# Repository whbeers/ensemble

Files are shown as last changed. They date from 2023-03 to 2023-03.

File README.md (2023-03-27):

# Ensemble Fuzz Effect

This is a semi-original octave fuzz, based most directly on the Death By Audio "Octave Clang", but with many of my own tweaks and additions. Designed in [KiCAD](https://www.kicad.org).

The board is built on the ["Noise Floor"](https://github.com/whbeers/noise_floor) pedal platform, which provides basic power protection, audio IO, and a footswitch with LED indicator.

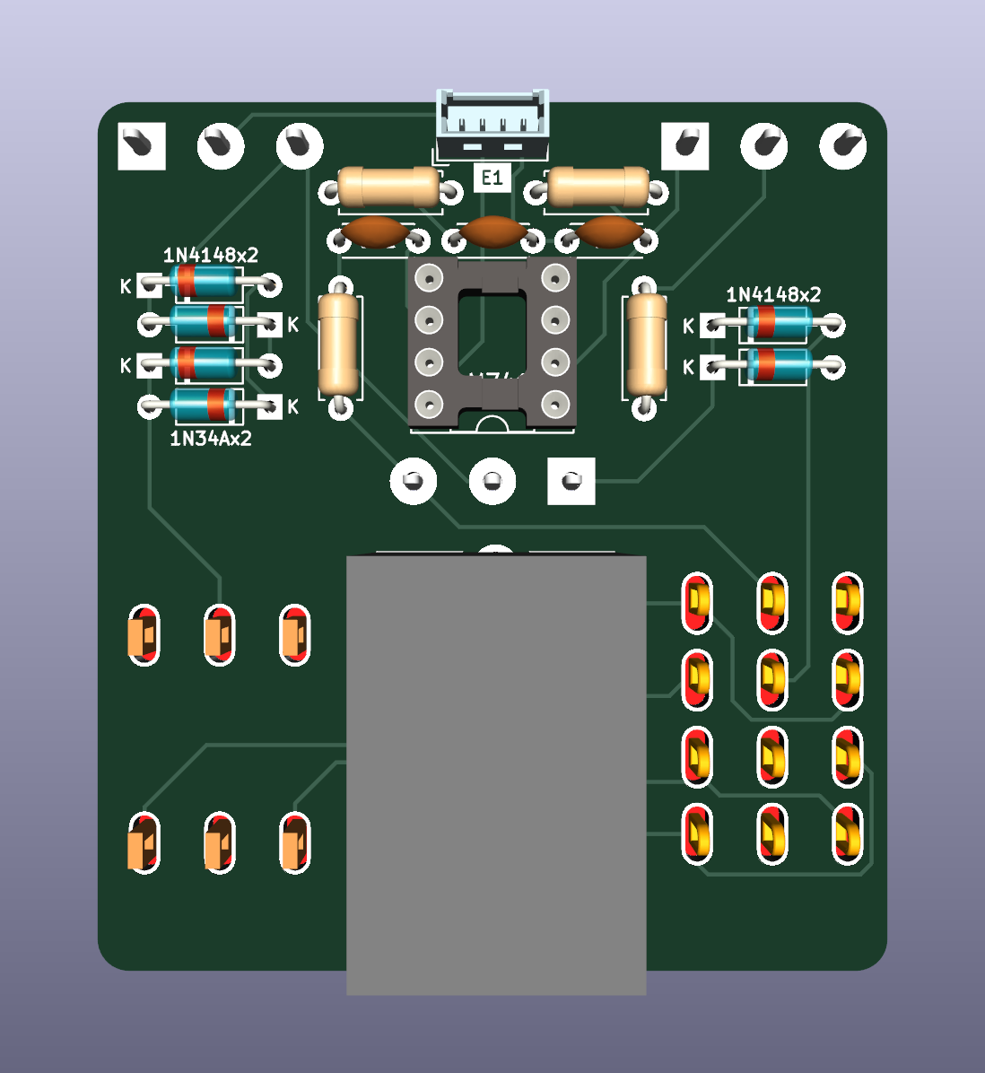
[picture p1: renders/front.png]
Front render

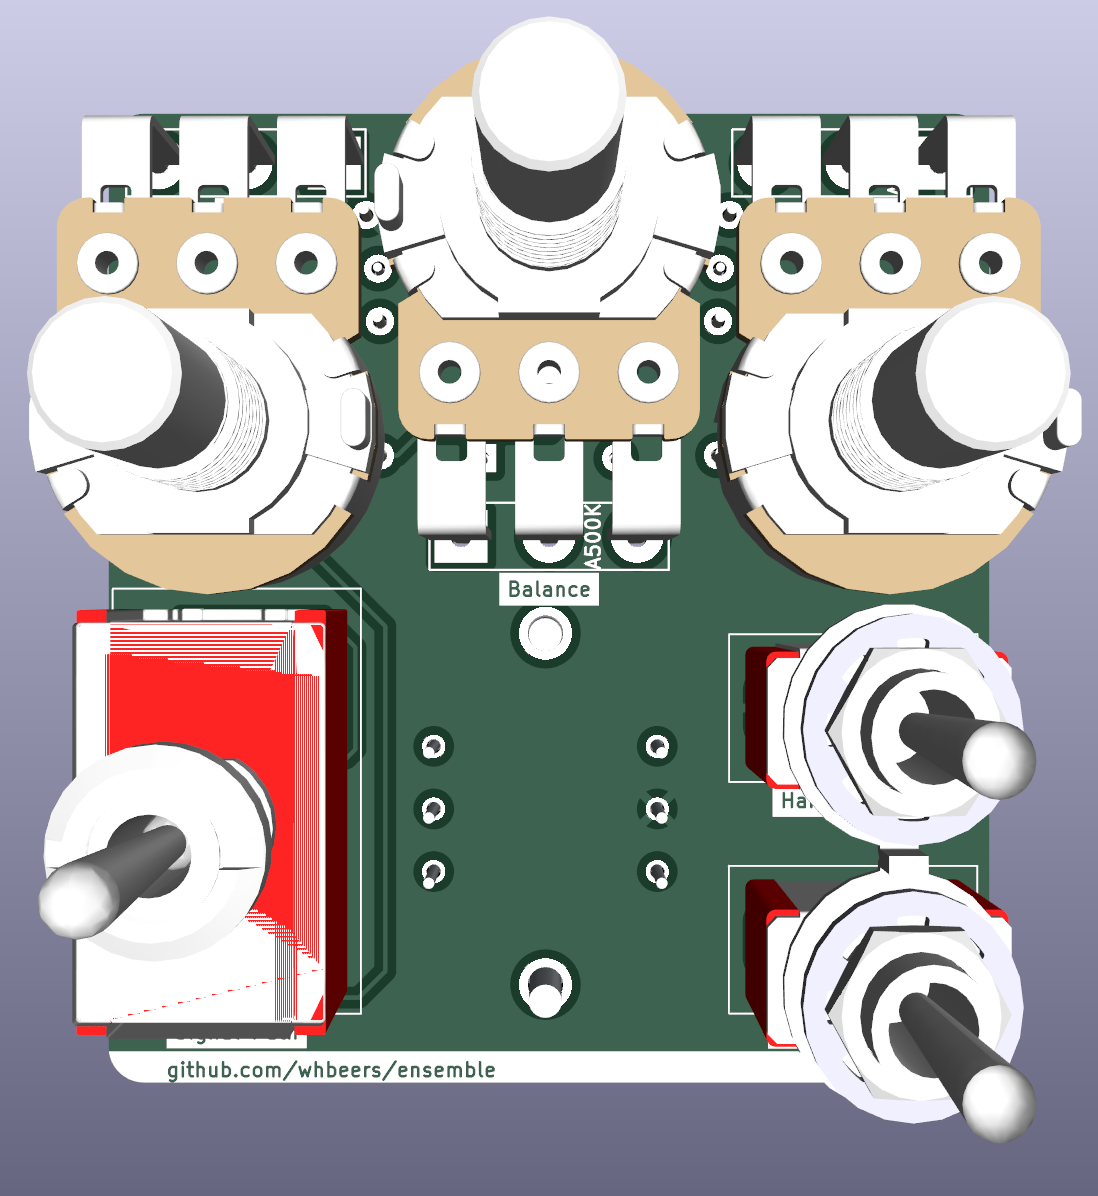
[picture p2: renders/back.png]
Back render

Schematic SVG
[Schematic PDF](schematics/ensemble-latest.pdf)

## Credit
I drew inspiration from a number of publicly-available octave fuzz schematics, but most directly public traces of the out-of-production [Death By Audio](https://deathbyaudio.com/) "Octave Clang" as portrayed in the PCBGuitarMania ["Death by Octaver" schematic](https://pcbguitarmania.com/product/death-by-octaver/), and by various contributors to the [thread at freestomboxes.org](https://www.freestompboxes.org/viewtopic.php?t=11122). I became interested in the effect after hearing the original maker, Oliver Ackermann, [demonstrate the Octave Clang](https://youtu.be/_RslAoTyIwk?t=2671) in a feature on EarthQuaker Devices' YouTube channel.

Thanks as always to the folks on the [freestompboxes.org](https://www.freestompboxes.org/) forum for feedback and suggestions.

Potentiometer 3D model courtesy [Vasily Kashirin](https://grabcad.com/vasily.kashirin-1).

SPDT toggle switch 3D model courtesy [Stephanie Schwecke](https://grabcad.com/stephanie.schwecke-1).

4PDT toggle switch 3D model courtesy [David Farrow](https://grabcad.com/library/4pdt-toggle-switch-1).

*I am not affiliated with any of the brands, sites, or products named in this overview.*

## My Modifications
Using what I could find out about Octave Clang as a basis, my circuit makes the following modifications:
 - added flexibility through three switchable voices for the octave stage:
   1. primary->secondary, full winding: a subtle driven octave effect
   2. secondary->primary, full winding: a clangorous metallic octave, most similar to the public demos of the Octave Clang
   3. secondary->primary, half winding: an even louder and more overt octave effect, thanks to the higher effective ratio of turns between secondary and primary windings. In this mode the octave effect is evident throughout most of the fretboard.
 - added a balance control to give further flexibility in the level of octave effect vs drive
 - added a (switchable) hard clipping stage to rein in the overall output level and add a very distinct, but still octave fuzz voice to the effect
 - tweaked component values to make the effect slightly more accessible across a range of volumes and gains (and to use more commonly-available values)
 - omitted the input-side tone control pot, as it tended to attenuate the signal to an unhelpful degree

## Versioning

My pcb designs utilize the following versioning scheme (I'll add to this as I produce more revisions):
 - v0.0XX: A candidate design that has not yet been produced and tested.
 - v0.XX: A design that has been produced, tested, and any initial errors addressed.

## Name
*The name "Ensemble" is a reflection of the nature of the effect (a blend of various octave fuzz and drive voices) and [security nerdery](https://www.usenix.org/system/files/sec19-chen-yuanliang.pdf).*

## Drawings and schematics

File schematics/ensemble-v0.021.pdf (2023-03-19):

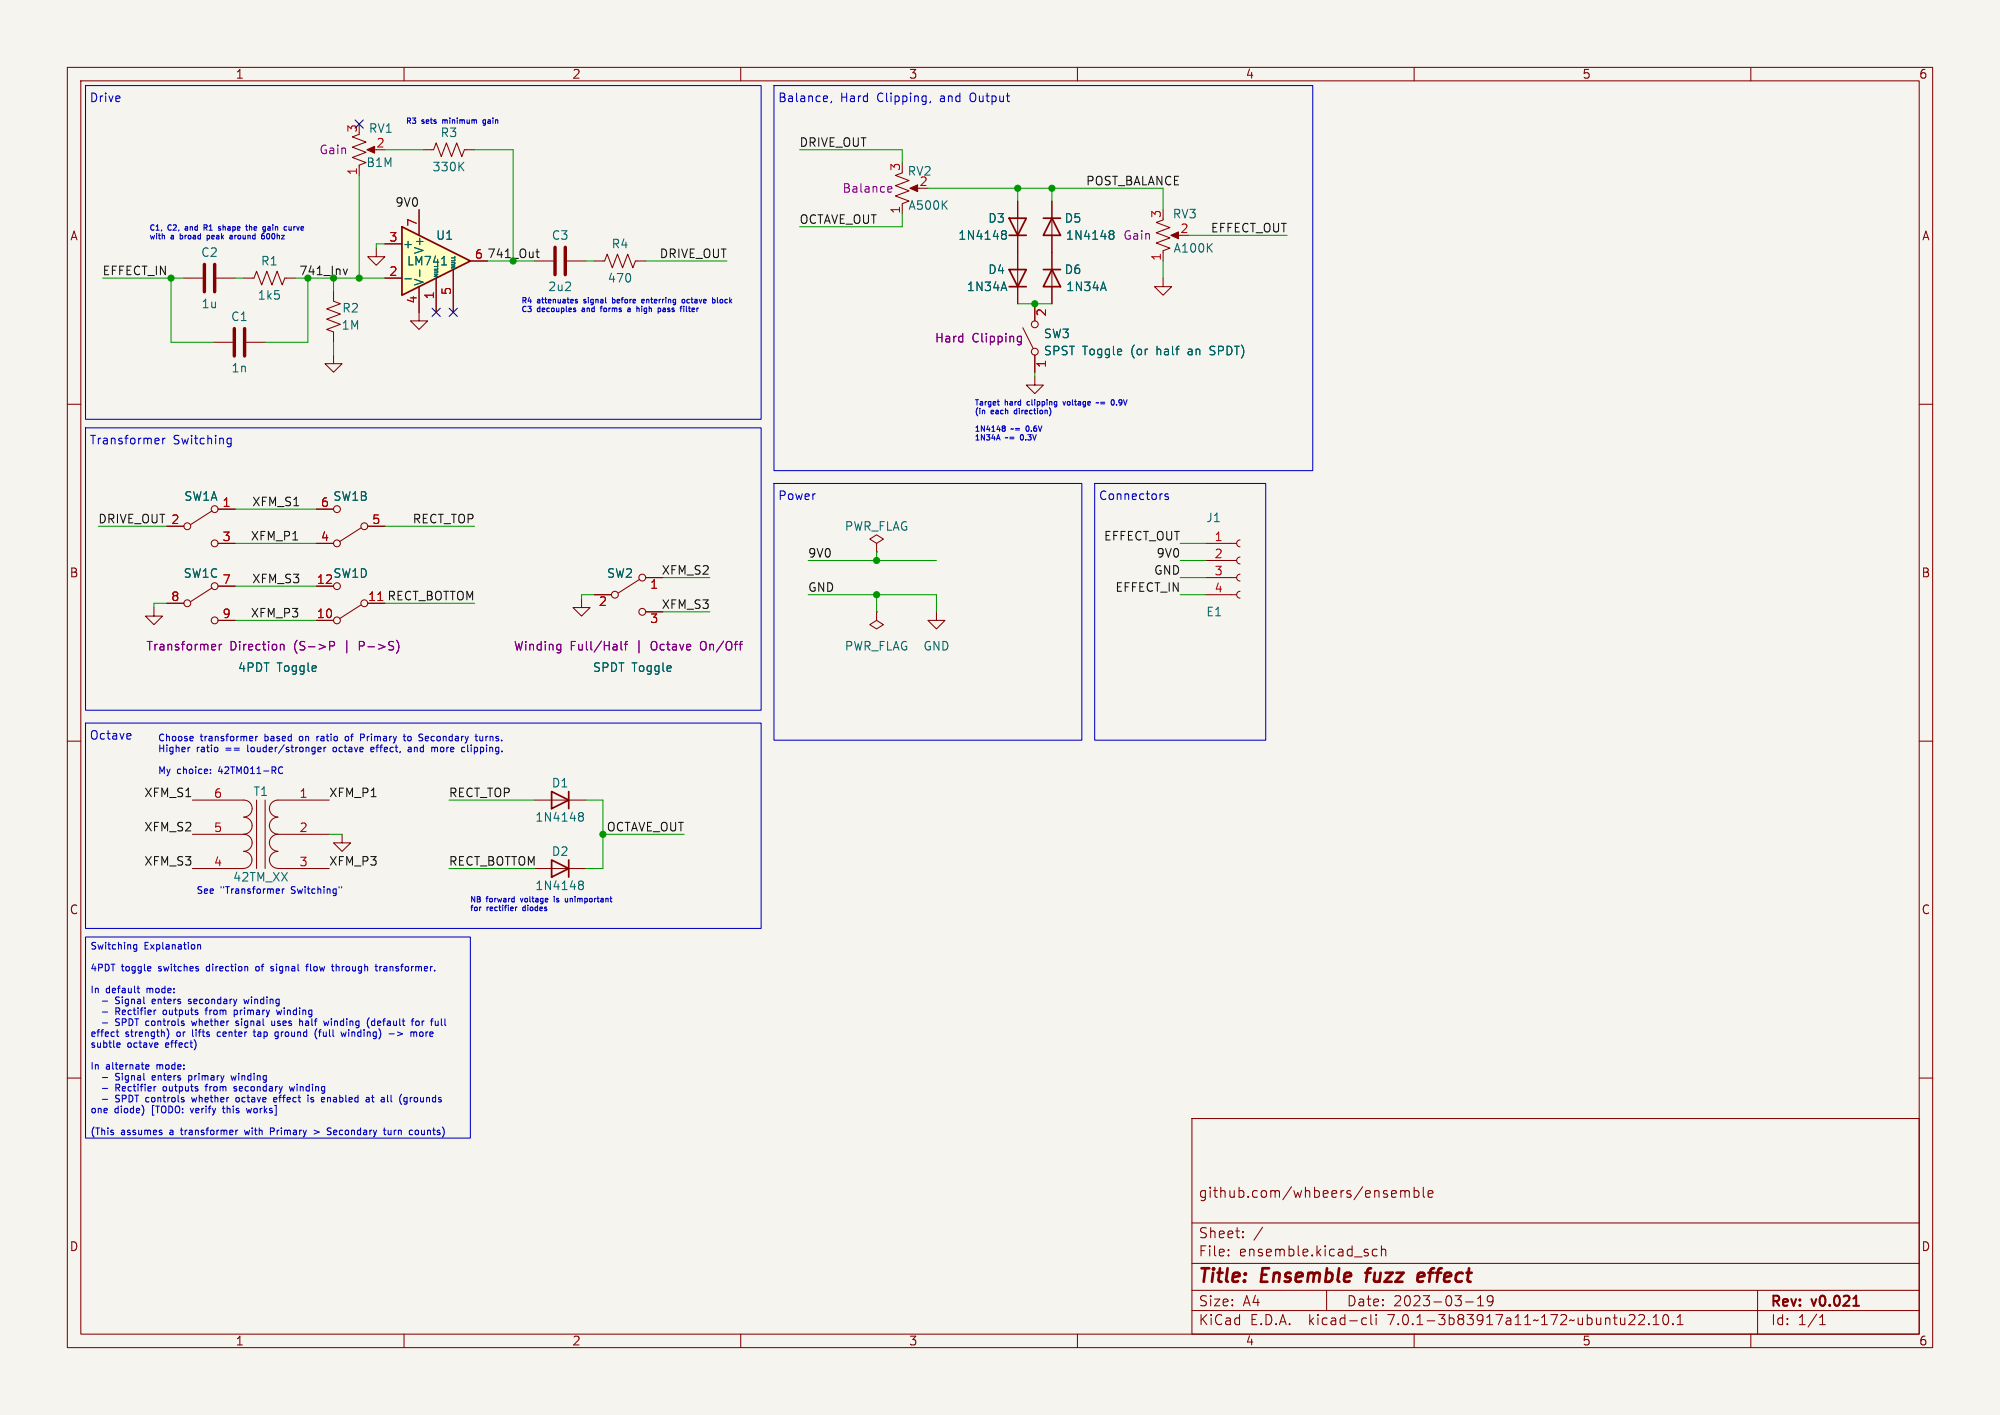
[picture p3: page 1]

SW3 SPST Toggle (or half an SPDT) Hard Clipping

Id: 1/1 Title: Ensemble fuzz effect File: ensemble.kicad_sch Sheet: / github.com/whbeers/ensemble GND

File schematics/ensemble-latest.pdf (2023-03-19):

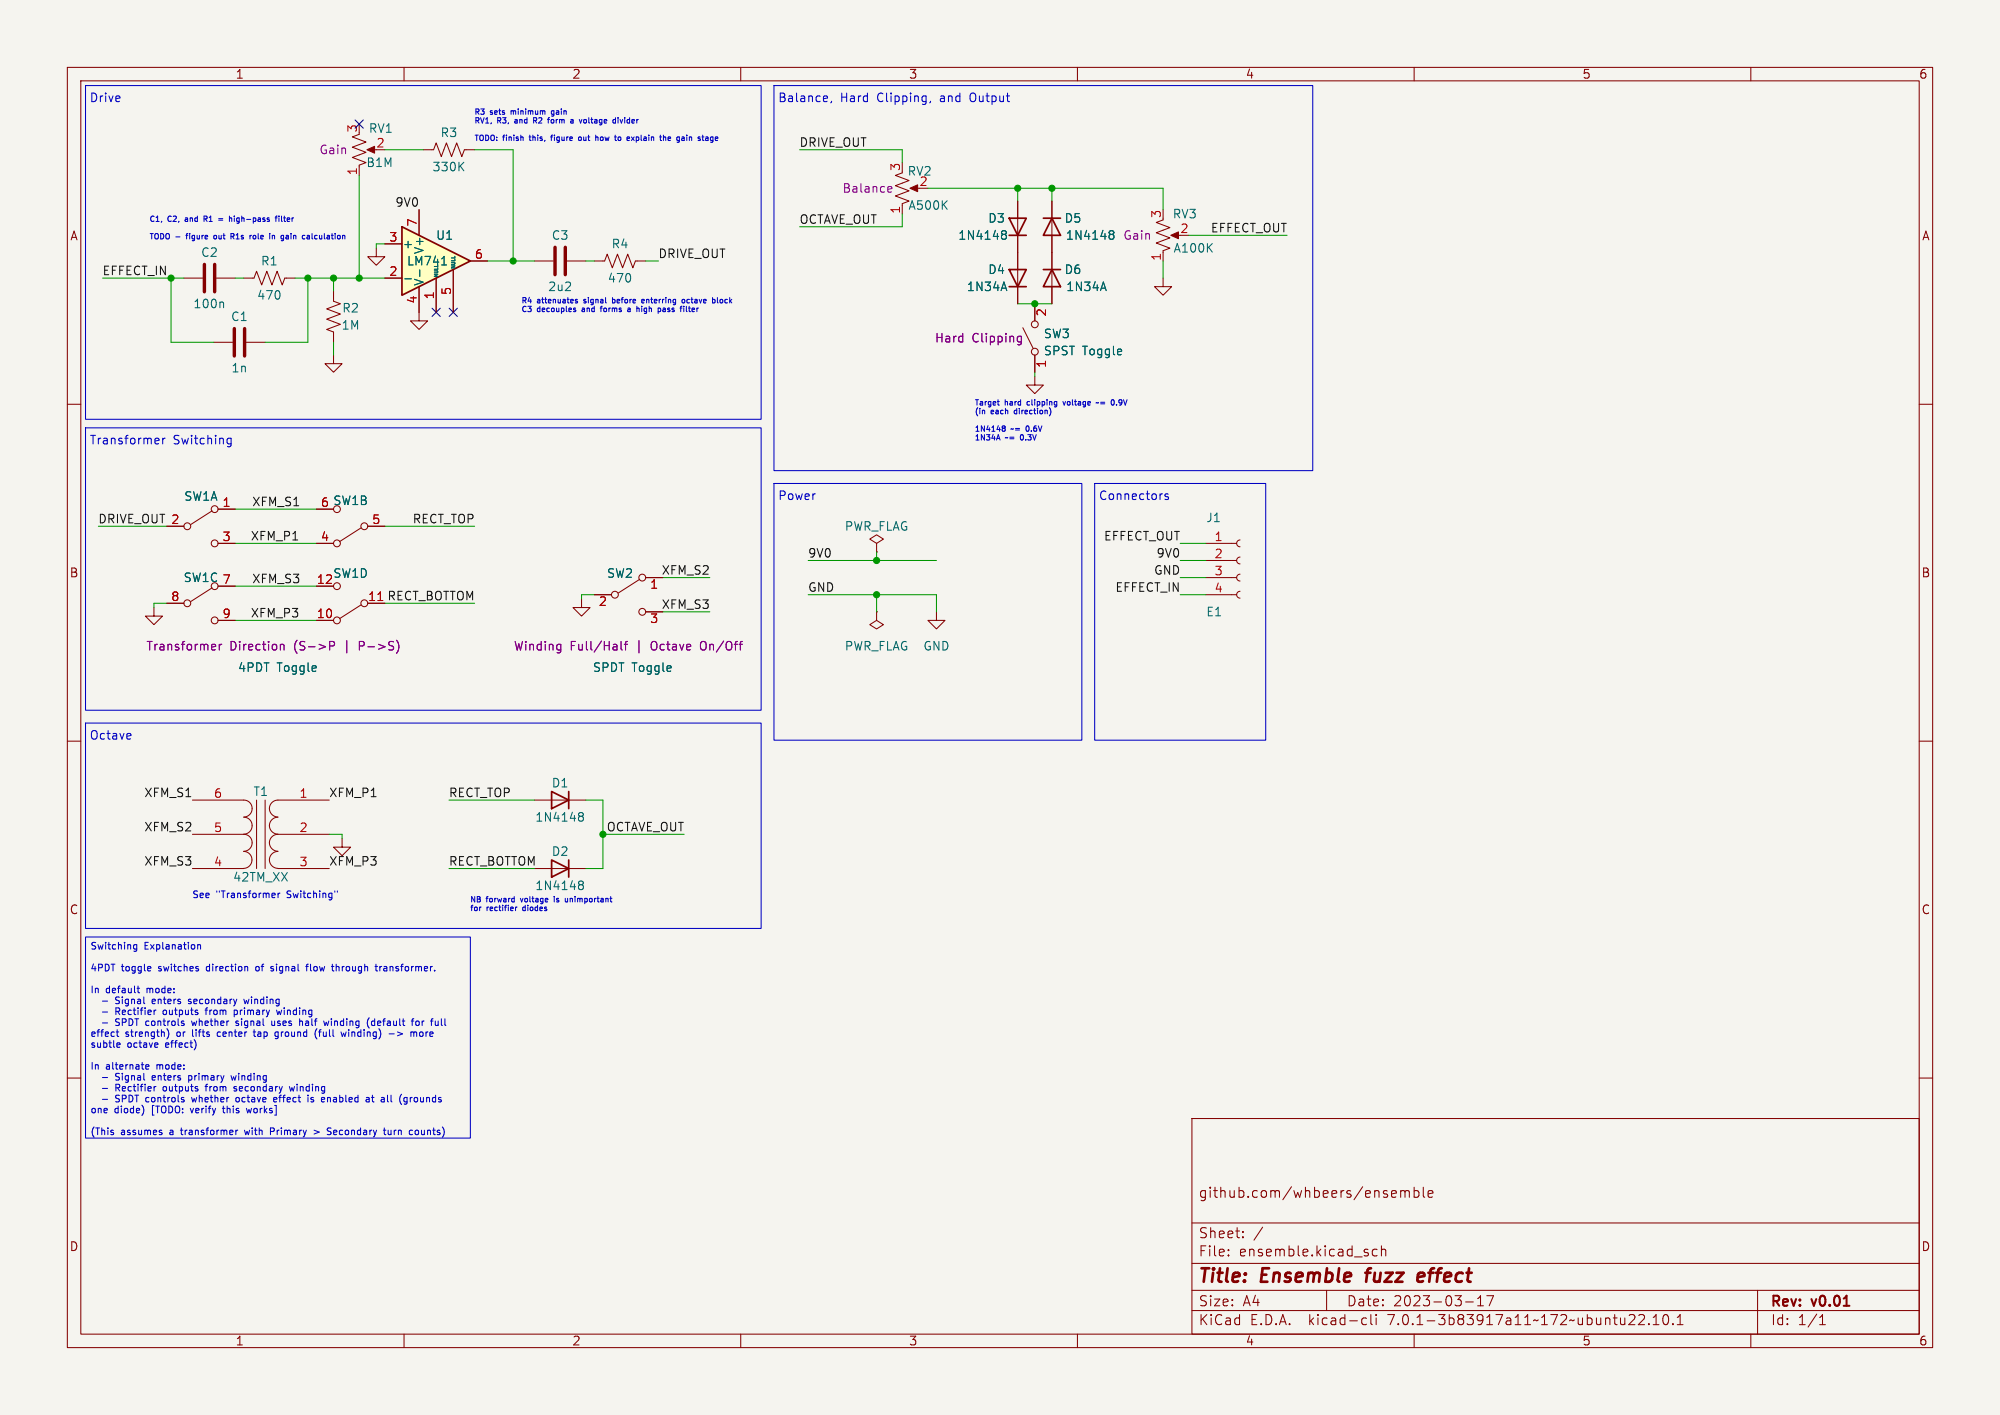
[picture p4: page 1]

1 2 SW3 SPST Toggle Hard Clipping D4

Id: 1/1 Title: Ensemble fuzz effect File: ensemble.kicad_sch Sheet: / github.com/whbeers/ensemble

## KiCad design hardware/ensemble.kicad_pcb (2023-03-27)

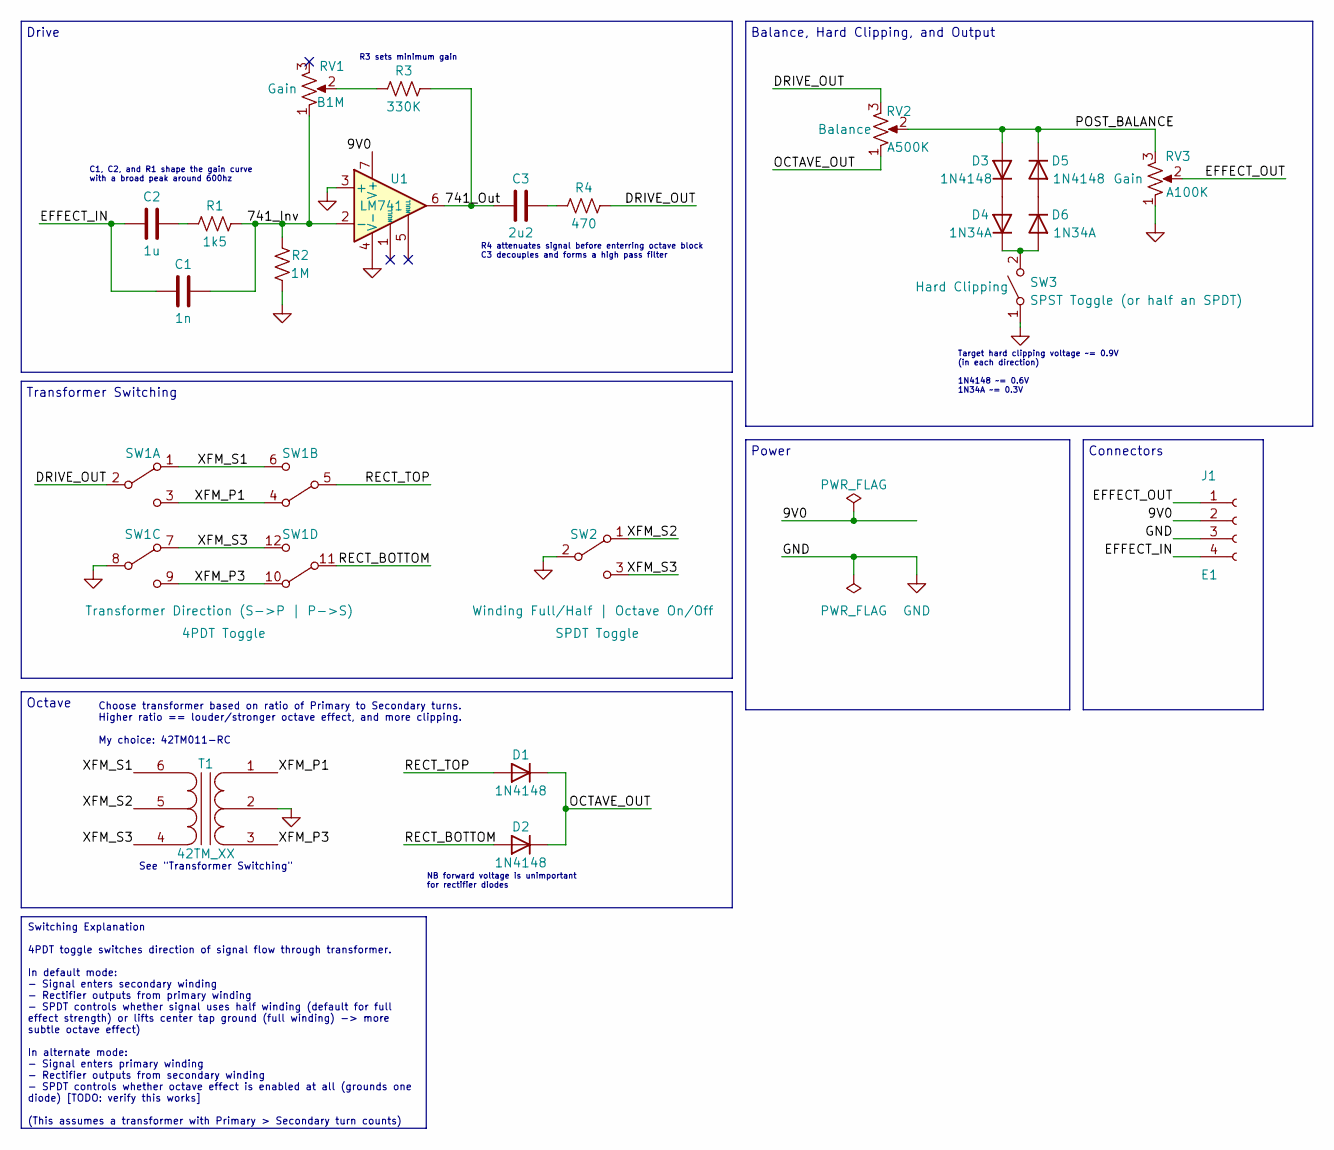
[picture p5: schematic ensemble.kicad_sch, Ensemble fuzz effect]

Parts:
C1: 1n; C_Disc_D4.3mm_W1.9mm_P5.00mm
C2: 1u; C_Disc_D4.3mm_W1.9mm_P5.00mm
C3: 2u2; C_Disc_D4.3mm_W1.9mm_P5.00mm
D1, D2, D3, D5: 1N4148; D_DO-35_SOD27_P7.62mm_Horizontal
D4, D6: 1N34A; D_DO-35_SOD27_P7.62mm_Horizontal
J1: E1; Molex_PicoBlade_53047-0410_1x04_P1.25mm_Vertical_with_3D_Mo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
R1: 1k5; R_Axial_DIN0207_L6.3mm_D2.5mm_P7.62mm_Horizontal
R2: 1M; R_Axial_DIN0207_L6.3mm_D2.5mm_P7.62mm_Horizontal
R3: 330K; R_Axial_DIN0207_L6.3mm_D2.5mm_P7.62mm_Horizontal
R4: 470; R_Axial_DIN0207_L6.3mm_D2.5mm_P7.62mm_Horizontal
RV1: B1M; Potentiometer_Single_3_Horizontal
RV2: A500K; Potentiometer_Single_3_Horizontal
RV3: A100K; Potentiometer_Single_3_Horizontal
SW1: 4PDT Toggle; SW_4PDT_SOLDER_LUGS
SW2: SPDT Toggle; SW_SPDT_SOLDER_LUGS
SW3: SPST Toggle (or half an SPDT); SW_SPDT_SOLDER_LUGS
T1: 42TM_XX; Transformer_42TM
U1: LM741; DIP-8_W7.62mm_Socket

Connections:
/9V0: J1.2, U1.7 (V+)
/741_Inv: C1.2, R1.1, R2.2, RV1.1, U1.2 (-)
/741_Out: C3.1, R3.2, U1.6
/DRIVE_OUT: R4.1, RV2.3, SW1.2 (A2)
/EFFECT_IN: C1.1, C2.1, J1.4
/EFFECT_OUT: J1.1, RV3.2
/OCTAVE_OUT: D1.1 (K), D2.1 (K), RV2.1
/POST_BALANCE: D3.2 (A), D5.1 (K), RV2.2, RV3.3
/RECT_BOTTOM: D2.2 (A), SW1.11 (D2)
/RECT_TOP: D1.2 (A), SW1.5 (B2)
/XFM_P1: SW1.3 (A3), SW1.4 (B1), T1.1 (AA)
/XFM_P3: SW1.9 (C3), SW1.10 (D1), T1.3 (AB)
/XFM_S1: SW1.1 (A1), SW1.6 (B3), T1.6 (SB)
/XFM_S2: SW2.1 (A), T1.5 (SC)
/XFM_S3: SW1.7 (C1), SW1.12 (D3), SW2.3 (C), T1.4 (SA)
GND: J1.3, R2.1, RV3.1, SW1.8 (C2), SW2.2 (B), SW3.1 (A), T1.2 (AC), U1.3 (+), U1.4 (V-)
unnamed: C2.2, R1.2
unnamed: C3.2, R4.2
unnamed: D3.1 (K), D4.2 (A)
unnamed: D4.1 (K), D6.2 (A), SW3.2 (B)
unnamed: D5.2 (A), D6.1 (K)
unnamed: R3.1, RV1.2

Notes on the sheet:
Switching Explanation 4PDT toggle switches direction of signal flow through transformer. In default mode: - Signal enters secondary winding - Rectifier outputs from primary winding - SPDT controls whether signal uses half winding (default for full effect strength) or lifts center tap ground (full w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
Transformer Switching
Target hard clipping voltage ~= 0.9V (in each direction) 1N4148 ~= 0.6V 1N34A ~= 0.3V
Choose transformer based on ratio of Primary to Secondary turns. Higher ratio == louder/stronger octave effect, and more clipping. My choice: 42TM011-RC
See "Transformer Switching"
Drive
C1, C2, and R1 shape the gain curve with a broad peak around 600hz
R4 attenuates signal before enterring octave block C3 decouples and forms a high pass filter
Balance, Hard Clipping, and Output
Power
R3 sets minimum gain
NB forward voltage is unimportant for rectifier diodes
Octave
Connectors

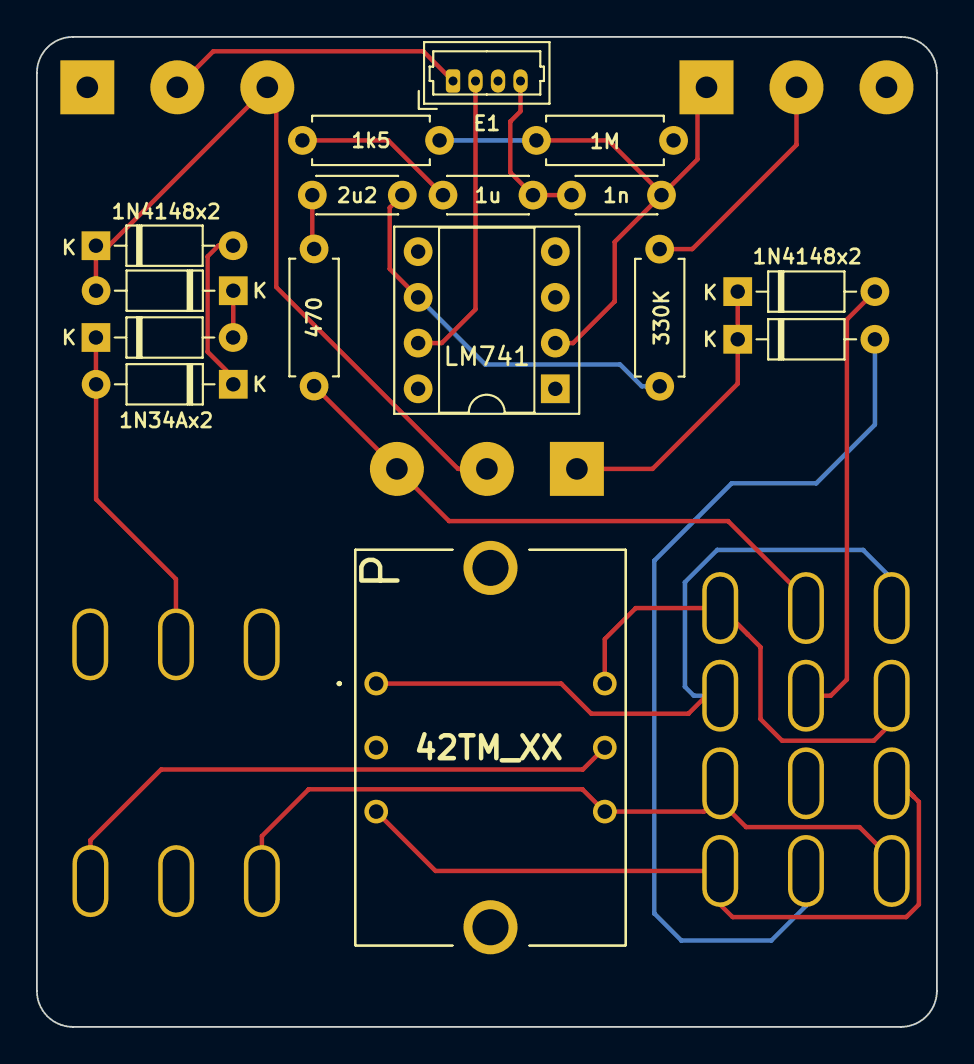
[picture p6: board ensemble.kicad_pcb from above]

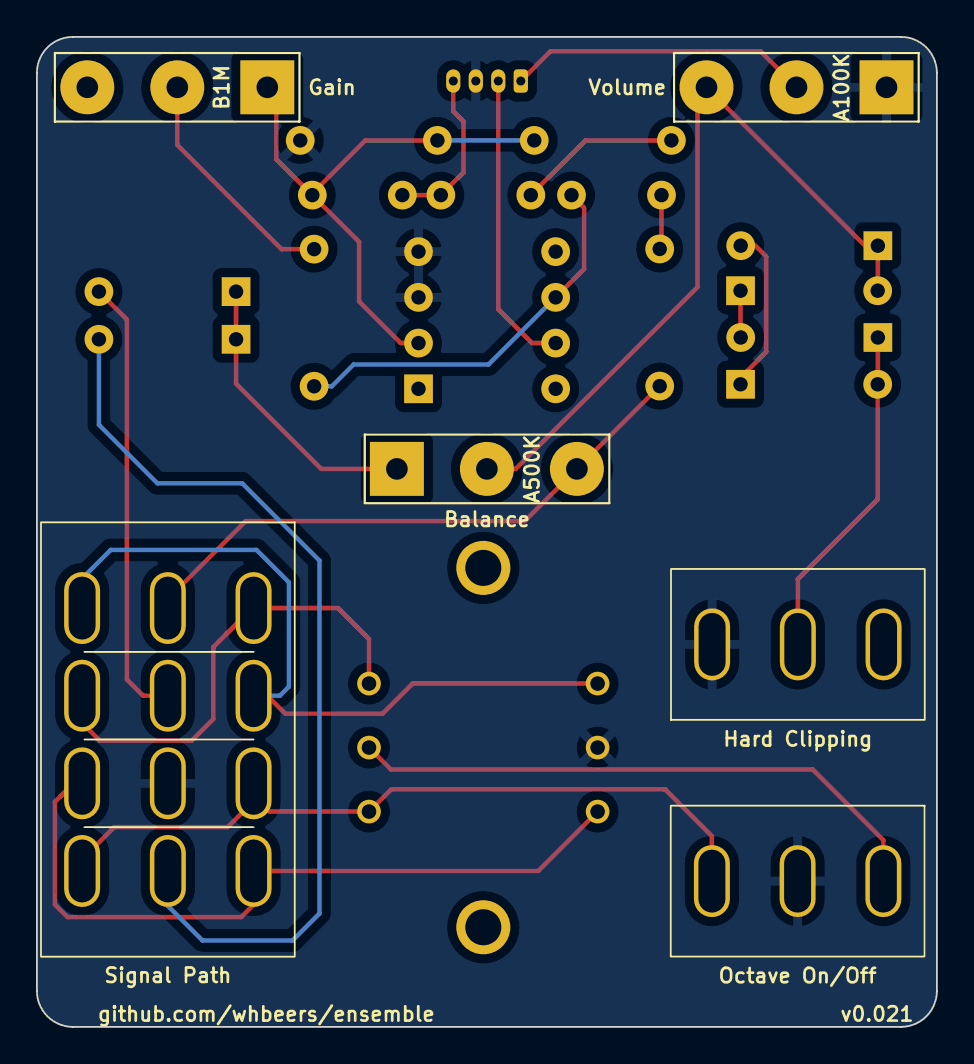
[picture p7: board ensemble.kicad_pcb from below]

Board: 2 copper layers, 50.0 x 55.0 mm, 22 parts (6 on the bottom side), 22 nets.

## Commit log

2023-03-17 initial schematic for Ensemble
    [ensemble.kicad_pcb, ensemble.kicad_sch]
2023-03-17 fix schematic background
2023-03-18 add footprints and models for all components
    [ensemble.kicad_pcb, ensemble.kicad_sch]
2023-03-18 initial layout
    [ensemble.kicad_pcb, ensemble.kicad_sch]
2023-03-18 add link and revision
    [ensemble.kicad_pcb]
2023-03-19 further iteration on layout
    [ensemble.kicad_pcb]
2023-03-19 fix 4pdt model alignment and initial routing
    [ensemble.kicad_pcb]
2023-03-19 tweak input-side filtering based on simulations, move to correct footprint for caps and diodes.
    [ensemble.kicad_pcb, ensemble.kicad_sch]
2023-03-19 slight routing and layout changes
    [ensemble.kicad_pcb, ensemble.kicad_sch]
2023-03-19 updated schematic
2023-03-19 one quick routing change
    [ensemble.kicad_pcb]
2023-03-19 getting closer to happy with the layout
    [ensemble.kicad_pcb]
2023-03-27 fix credit for models
    [ensemble.kicad_pcb]
